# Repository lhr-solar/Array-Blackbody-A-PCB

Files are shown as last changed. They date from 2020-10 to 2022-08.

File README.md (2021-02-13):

# RTD and Irradiance Sensor Board

This repository contains the following files for the RTD/Irradiance Sensor HW:

- Schematic
- Layout
- Datasheets

Also a good resource is the
[Irradiance/RTD Board Parts List](https://docs.google.com/spreadsheets/d/1edYMT-QyYtll1uI2qYTIh2mhwAQPUqRFkjrvS2jViS4/edit?usp=sharing);
this is the source of truth for the schematic and layout and should be consulted
and updated by anyone doing revisions on the board. As good practice, make sure
your updates to the parts list, when finalized, gets a new named version in the
version history.

A couple other important sections for engineers who are improving this board are
below.

- Versioning
- Maintainers
- Errata and Changes
- Suggested Improvements
- Ordering Instructions
- Assembly Instructions

---

## Maintainers

The last maintainer of this project was Matthew Yu (Array Lead 2020) as of
12/13/2020. His email is matthewjkyu@gmail.com.

Also a useful point of contact is Professor Gary Hallock, who advised Matthew
and worked with the several former senior design teams and solar car class
groups who developed this board.

---

## Versioning, Errata, and Changes

This board has separate versions for the schematic, parts list, and layout. We
use [semantic versioning](https://semver.org/) to denote between versions.

We also follow the mutually inclusive versioning procedure agreed upon in this
[issue](https://github.com/lhr-solar/Electronics/issues/40).

### Versioning

The board schematic is currently on **Version 1.0.0**.

The board layout is currently on **Version 1.0.0**.

The parts list is currently on **Version 1.0.0**.

### Schematic

- **Rev 1.0.0**:
  - None as of 12/13/2020, but then the board hasn't been assembled and tested
    yet.

### Layout

- **Rev 1.0.0**:
  - None as of 12/13/2020, but then the board hasn't been assembled and tested
    yet.

### Parts List

- **Rev 1.0.0**:
  - Populated and ready for ordering (sans snubber caps and resistors).

---

## Suggested Improvements

This is a list of changes we can make to the board in future versions to improve
it in various ways. Some of these are functional, others are purely aesthetic.

1. Use a multiplexer to route RTDs to a single RTD-to-digital-converter chip.
   This would reduce our 8 chips into 1 and potentially cut down board size by
   more than 50%. This may also have advantages for digital signal integrity by
   drastically reducing trace length. Oh, and a large cost reduction.
2. Rename the project from RTDTemp to RTD_Irradiance_Board. Make sure you do
   this on a feature branch of the repo so you can revert to a previous version
   if you break things.

---

## Ordering Instructions

Ordering the board will vary from distributor to distributor; some will take the
KiCAD project directly, others require Gerber files. If they require gerber
files, some will require specific naming conventions for each layer.

If they take KiCAD projects directly, that should be what you prefer. Package
`RTDTemp.pro`, `RTDTemp.kicad_pcb`, and `RTDTemp.sch` together into a zip file (i.e.
`RTDTemp.zip`) and upload it. Double check the layers they detect to ensure that
everything looks correct. If they aren't interpreted correctly, use the Gerber
files instead.

The Gerber files are grouped together into the 'Gerber/' folder. The layers you
want are:

- Front/Top Copper,
- Back/Bottom Copper,
- Front/Top Mask,
- Back/Bottom Mask,
- Front/Top Silkscreen,
- Back/Bottom Silkscreen,
- Edge Cuts (i.e. board outline)

You may also want the Front/Top Fabrication layer if you're submitting to a
manufacturer that will place and solder your components for you, but that's not
strictly necessary.

The Gerber files I've generated should be named appropriately for most
manufacturers, however they may prefer slightly different conventions. Double
check their requirements, make any necessary adjustments to file names, then zip
up all of the gerber files and upload that.

Some examples of alternate conventions:

- Some want the board outline to have the extension '.gko'.
- Some want all layers to have the same base name (i.e. 'RTDTemp.gbl',
  'RTDTemp.gbs', etc.).
- Some want the drill files combined (in which case you'll need to regenerate
  the drill file with plated and nonplated holes combined).
- Some want the drill files to have the extension '.txt'.

If you need to regenerate the Gerber files for whatever reason, the defaults
saved to the PCB file should be sufficient. However, in case these are lost,
here are the important parts:

- Set Output Directory to "Gerber/"
- Uncheck "Plot sheet reference on all layers"
- Check "Exclude PCB edge layer from other layers"
- Check "Use Protel filename extensions"

-or the drill files:

- Set Output Directory to "Gerber/"
- Set Drill Units to "Inches"
- Set Zeros Format to "Decimal format"
- Set Drill Map File Format to "PostScript"
- Uncheck "Mirror y axis"

These settings should work, but double check with your manufacturer that these
settings are correct before you order.

---

## Assembly and Testing

The board should be assembled and tested in sections to ensure proper
functioning. Assembly should go through the following sections in order:

1. Power Regulation
2. LEDs
3. Nucleo Connections
4. RTD Sensors
5. Irradiance Sensors
6. CAN

### Step by Step Instructions

It's highly recommended to pull up the schematic and layout side by side while
assembling and testing the board. As a tip, you can click on the schematic
symbol, and if the layout window is open, it'll jump to that part on the layout.
Also hide everything except the Silkscreen or Fabrication layer (of the right
side of the PCB) to remove any clutter from the layout.

Also, if you find any discrepancies between these instructions and the board
layout, please file a PR or issue so it can be fixed!

1. Initial Board Checks

   Before installing anything, check for power shorts where there shouldn't be:
   - Between Car Power +12V and GNDPWR.
   - Between Device Power +9VA and GNDREF.
   - Between Car Power +12V and Device Power +9VA.
   - Between Car Power GNDPWR and Device Power GNDREF.
   - Between CAN Iso Vout and GndOut
   - Between CAN Iso Vin and GndIn
   - Between CAN Iso Vout and Vin
   - Between CAN Iso GndOut and GndIn

   Other important shorts to check for and eliminate:
   - Between CAN H and L
   - On each Nucleo board, between A4 and D4 (shorted by SB18)
   - On each Nucleo board, between A5 and D5 (shorted by SB16)

2. Assembling Power Regulation
   1. Solder the smallest components first: L1, C1, C2, C3, C4. These can be
      done in any order.
   2. Solder test points: TP2, TP3, TP4, TP5. These can be done in any order.
   3. Solder power regulator U2.
   4. Solder the connector J3.
   5. Test for the following shorts:
      - Between Car Power +12V and GNDPWR.
      - Between Device Power +9VA and GNDREF.
      - Between Car Power +12V and Device Power +9VA.
      - Between Car Power GNDPWR and Device Power GNDREF.
      - Between pins on U2.
   6. Connect +12V to the connector and verify that +9VA is at TP4.
   7. As a bonus, somehow make some noise at +12V and see how stable +9VA is.

3. LEDs
   1. Solder the smallest components first: R3 - R8 and LED1 - LED6. You get the
      drill by now.
   2. Check for shorts across each resistor-LED pair. As a tip, the LED
      reference number is always two less than the resistor reference number.
   3. Further testing on these will occur in the next step.

4. Nucleo Connections
   1. Solder the smallest components first: SW, J1, J2, R1, R2. You get the
      drill by now.
   2. Solder the headers for the Nucleo (U1) and make sure they are upright.
   3. Test for the following shorts:
      - Across SW1 (shorts only when pushed)
      - Between pins on U1 (as a bonus)
   4. Plug in the Nucleo and then test for shorts between D4 and A4 and between
      D5 and A5. If there are shorts here, you will need to remove SB18 or SB16,
      respectively, from the Nucleo board.

      **YOU MUST DO THIS FOR EVERY UNIQUE NUCLEO YOU PLUG INTO THE BOARD.**

   5. Load up the Nucleo with a test program to cycle LED pins and outputs a PWM
      signal with a non-trivial duty cycle and see if they light up/are correct
      on an O-scope. Unplug the Nucleo from USB, and connect 12V to the Car
      Power Connector J1 (But not both!). Make sure the Nucleo powers on again
      and the test program works as expected.
   6. Remove the Nucleo and all sources of power before further assembly.

5. RTD Sensors

   It's recommended to do one of these sensors at a time.

   1. Pick a sensor. We'll use the first sensor (sensor 0) as an example.
   2. Solder the smallest components first: RTD0_C1, RTD0_C2, RTD0_C3, RTD0_R1.
   3. Solder the chip RTD0_U1.
   4. Solder the connector RTD0_J1.
   5. Test for shorts across the pins on U1, and that we have a connection
      between pads 2 and 3 and the +3.3V pin of the Nucleo (after
      plugging it in, but not powering it).
   6. You can then load up a test program to communicate with the chip via SPI.
      If you have an Arduino Uno, you can try using this
      [test program](https://github.com/olewolf/arduino-max31865)
      written by `olewolf`. You can use the Nucleo headers to access the
      relevant pins of the chips - the pin mapping is described in the
      `Examples/Read_Temperature/Read_Temperature.ino`.
   7. If test software for the Nucleo has been written, you can potentially skip
      step 6 and use the Nucleo with the software flashed directly. Although
      going back to step 6 could be useful for debugging if you have issues
      here.

6. CAN Circuit

   1. Solder chip U3 **first** and test for shorts across adjacent pins.
   2. Solder the smallest components: C5 - C12, L2, L3, R10, R11.
   3. Solder bridge R9.
   4. Solder test points TP5 - TP12.
   5. Solder the chip U4.
   6. Solder the termination header JP1.
   7. Solder the CAN Connectors J4, J5.
   8. Test for the following shorts:
      - Between CAN_H and CAN_L.
      - Between CAN_Tx, CAN_Rx.
      - +5V and GNDREF (Power side).
      - 5V and GND (CAN side).
      - Across adjacent pins in U3, U4.
   9. Plug in the Nucleo, connect J4/J5 to a CAN bus, and run a CAN
      communication test to ensure that the installed CAN circuitry is
      functional.
   10. Remove any power, the Nucleo, and then CAN connections before further
       assembly.

7. Post checks

   Now that you've made it to the end (we hope) of assembly and preliminary
   testing, you should do a couple things before running full RTDTemp tests and
   running RTDTemp algorithms on it.

   1. First, check the board for obvious soldering defections like burnt traces
      or exposed component legs. Make sure those still work. For any solder
      bridges that shouldn't fix, you should fix them. Or get somebody who's
      better than you to fix them.
   2. Check to see if you have any remaining parts hiding in the pile of
      plastic packages you probably received. Any remaining parts should
      probably be a cause for concern (unless you knew you were going to blow
      something and had the foresight to get extra) and you should definitely
      see where they might have come from.

      The RTDTemp Parts list is **THE** definite source of truth, and tells you
      where each part is tied to which reference and thus their position on the
      layout. Check there first before running to the electrical lead to help
      you.
   3. It might be a good idea if you're bored to run any electrical/short tests
      that were described earlier in these instructions. There's always a small
      chance that some assembly you did later on broke/removed/damaged previous
      parts.

You now have a completed RTDTemp (I hope) and I wish you luck in your future
solar car endeavors!

This assembly guide was last modified *12/13/2020* by **Matthew Yu**.

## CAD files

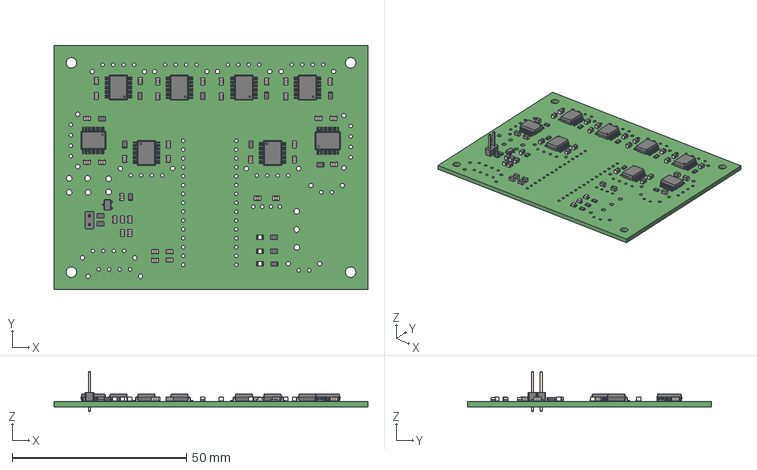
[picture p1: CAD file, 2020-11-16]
RTDTemp.step
90.0 x 70.0 x 11.5 mm

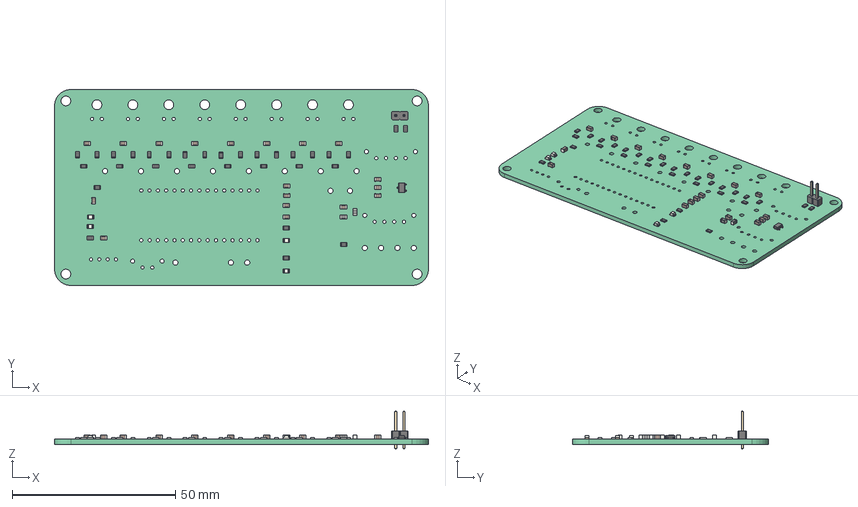
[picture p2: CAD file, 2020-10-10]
RTD.step
114.5 x 60.0 x 11.5 mm
Local_CS_a89f
Pcb_a89f
PCB_Sketch_a89f
U7_SOT_23W_5E47511B
JP1_PinHeader_1x02_P254mm_Vertical_5E474AD0
C16_C_0805_2012Metric_5E475BC1
C15_C_0805_2012Metric_5E4747D3
C14_C_0805_2012Metric_5E4747C2
C13_C_0805_2012Metric_5E4747B1
C7_C_0805_2012Metric_5E4003D7
C6_C_0805_2012Metric_5E4003C6
R32_R_0805_2012Metric_5E370AB1
R31_R_0805_2012Metric_5E370AA0
R30_R_0805_2012Metric_5E370A8F
R29_R_0805_2012Metric_5E370A7E
R28_R_0805_2012Metric_5E370A6D
R27_R_0805_2012Metric_5E370A5C
R26_R_0805_2012Metric_5E370A4B
R24_R_0805_2012Metric_5E370A3A
R23_R_0805_2012Metric_5E370A29
R19_R_0805_2012Metric_5E370A18
R18_R_0805_2012Metric_5E370A07
R17_R_0805_2012Metric_5E3709F6
R16_R_0805_2012Metric_5E3F5E9A
R15_R_0805_2012Metric_5E3709D4
R13_R_0805_2012Metric_5E3709C3
R12_R_0805_2012Metric_5E3709B2
R11_R_0805_2012Metric_5E3709A1
R8_R_0805_2012Metric_5E370990
R6_R_0805_2012Metric_5E37097F
R5_R_0805_2012Metric_5E37096E
R4_R_0805_2012Metric_5E3EF439
R3_R_0805_2012Metric_5E37094C
R2_R_0805_2012Metric_5E3F3787
R1_R_0805_2012Metric_5E37092A
C19_C_0805_2012Metric_5E3F6AFD
C18_C_0805_2012Metric_5E3707F4
C17_C_0805_2012Metric_5E3707E3
C5_C_0805_2012Metric_5E3707D2
C4_C_0805_2012Metric_5E3EF89F
C3_C_0805_2012Metric_5E3707B0
C2_C_0805_2012Metric_5E37079F
C1_C_0805_2012Metric_5E37078E
C9_C_0805_2012Metric_5E49071F
C10_C_0805_2012Metric_5E49072F
C11_C_0805_2012Metric_5E49073F
C12_C_0805_2012Metric_5E49074F
L2_L_0805_2012Metric_5E490782
L3_L_0805_2012Metric_5E490792
LED3_LED_0805_2012Metric_5E4907A2
LED7_LED_0805_2012Metric_5E4907B4
LED8_LED_0805_2012Metric_5E4907C6
LED9_LED_0805_2012Metric_5E4907D8
R9_R_0805_2012Metric_5E4907EA
R10_R_0805_2012Metric_5E4907FA
R14_R_0805_2012Metric_5E49080A
R20_R_0805_2012Metric_5E49081A
R21_R_0805_2012Metric_5E49082A
R22_R_0805_2012Metric_5E49083A
R25_R_0805_2012Metric_5E49084A

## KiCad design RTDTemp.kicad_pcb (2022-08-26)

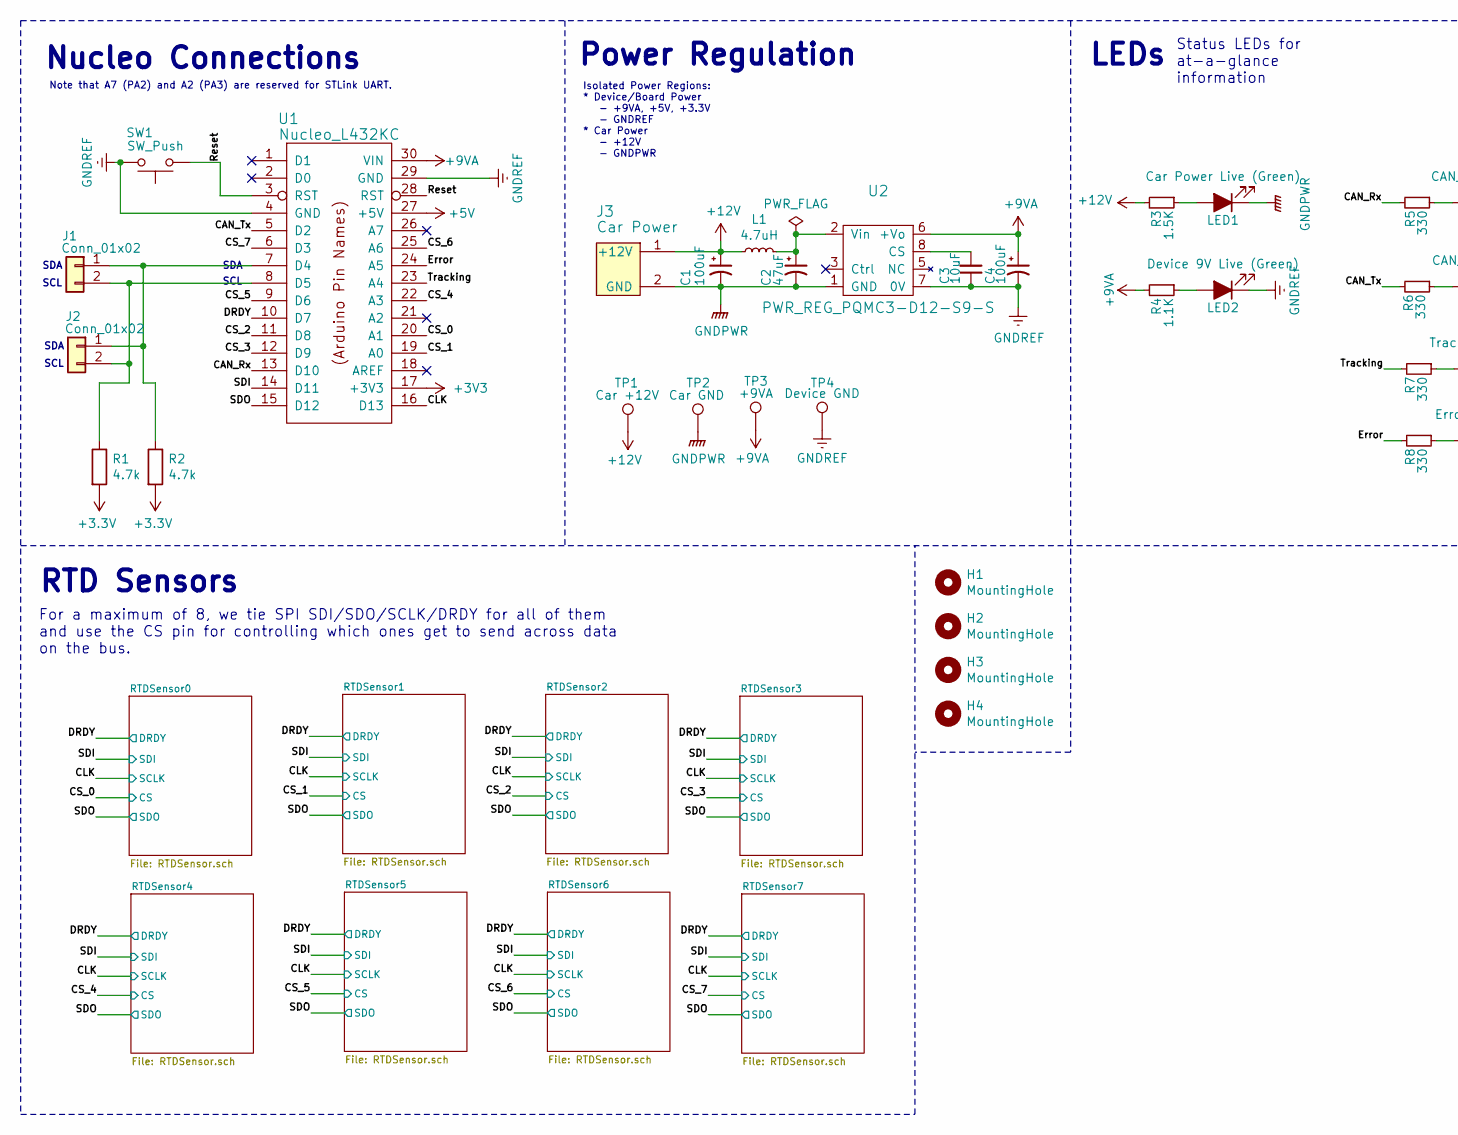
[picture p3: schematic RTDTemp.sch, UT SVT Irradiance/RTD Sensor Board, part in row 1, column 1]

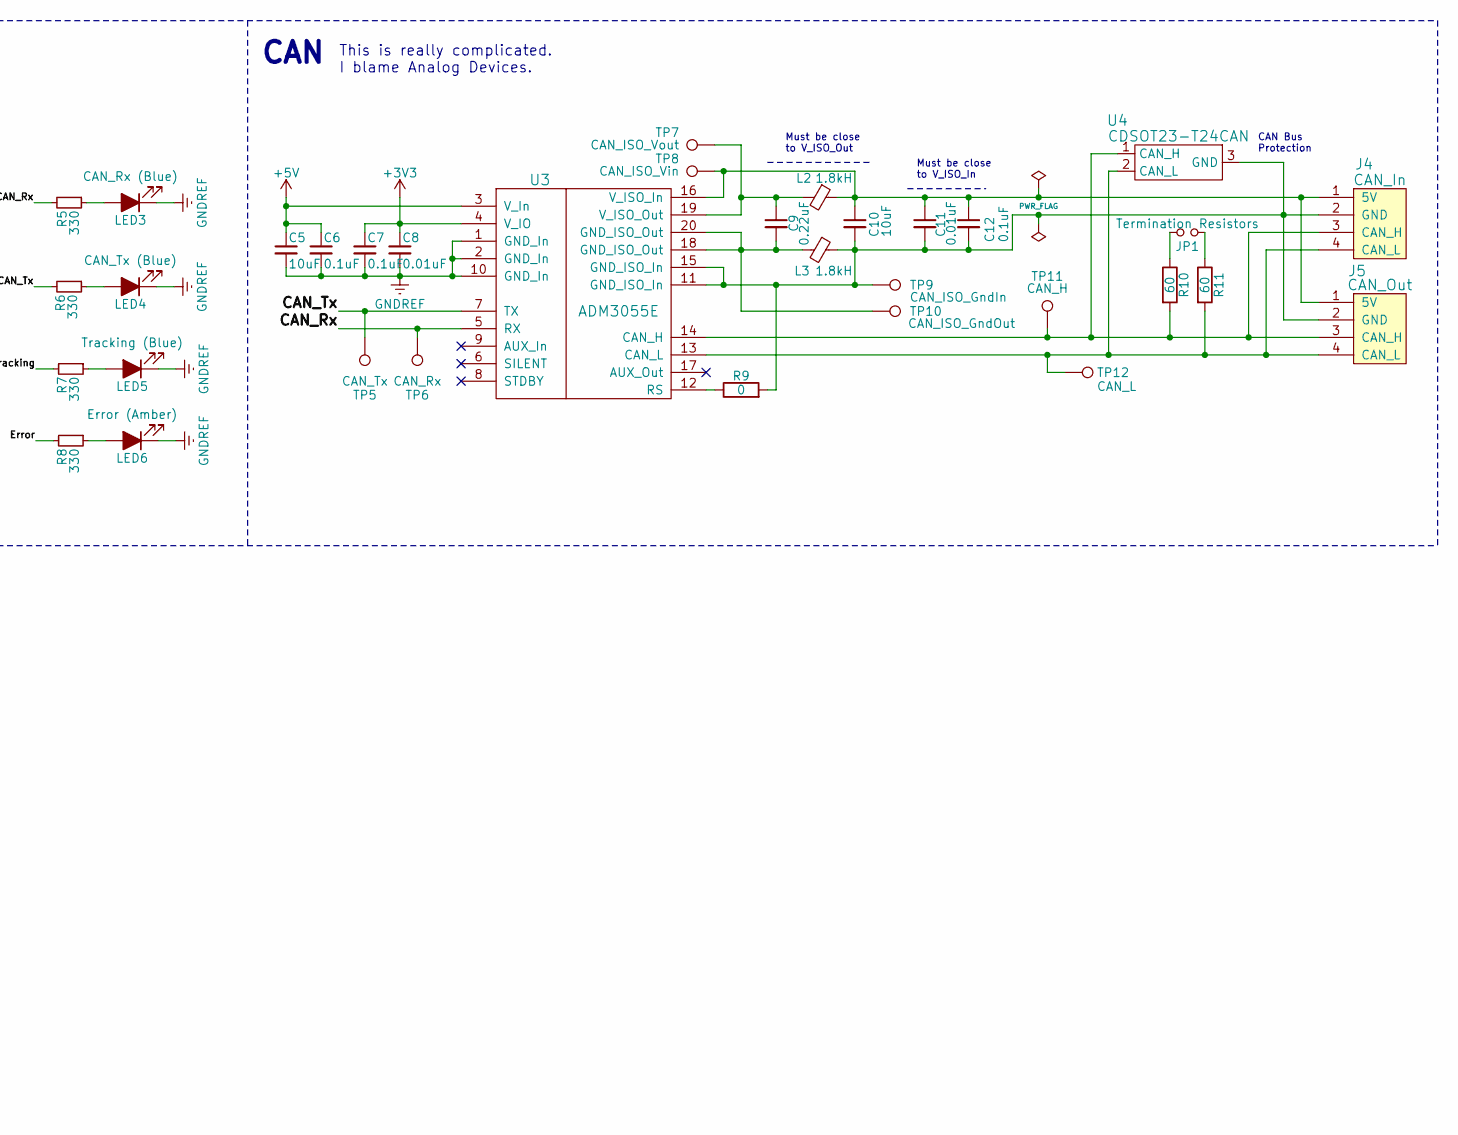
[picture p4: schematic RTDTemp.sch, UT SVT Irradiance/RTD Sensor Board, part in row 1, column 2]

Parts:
C1, C4: 100uF; C_1210_3225Metric
C2: 47uF; C_1210_3225Metric
C3, C5, C10: 10uF; C_0805_2012Metric
C6, C7, C12: 0.1uF; C_0805_2012Metric
C8, C11: 0.01uF; C_0805_2012Metric
C9: 0.22uF; C_0805_2012Metric
H1, H2, H3, H4: MountingHole; MountingHole_3mm
J1, J2: Conn_01x02; Molex_Micro-Fit_3.0_43650-0215_1x02_P3.00mm_Vertical
J3: Car Power; Molex_Micro-Fit_3.0_43650-0215_1x02_P3.00mm_Vertical
J4: CAN_In; Molex_Micro-Fit_3.0_43650-0415_1x04_P3.00mm_Vertical
J5: CAN_Out; Molex_Micro-Fit_3.0_43650-0415_1x04_P3.00mm_Vertical
JP1: Termination Resistors; PinHeader_1x02_P2.54mm_Vertical
L1: 4.7uH; L_0805_2012Metric
L2, L3: 1.8kH; L_0805_2012Metric
LED1: Car Power Live (Green); LED_0805_2012Metric
LED2: Device 9V Live (Green); LED_0805_2012Metric
LED3: CAN_Rx (Blue); LED_0805_2012Metric
LED4: CAN_Tx (Blue); LED_0805_2012Metric
LED5: Tracking (Blue); LED_0805_2012Metric
LED6: Error (Amber); LED_0805_2012Metric
R1, R2: 4.7k; R_0805_2012Metric
R3: 1.5K; R_0805_2012Metric
R4: 1.1K; R_0805_2012Metric
R5, R6, R7, R8: 330; R_0805_2012Metric
R9: 0; R_0805_2012Metric
R10, R11: 60; R_0805_2012Metric
SW1: SW_Push; SW_PUSH_6mm
TP1: Car +12V; TestPoint_Keystone_5005-5009_Compact
TP2: Car GND; TestPoint_Keystone_5005-5009_Compact
TP3: +9VA; TestPoint_Keystone_5005-5009_Compact
TP4: Device GND; TestPoint_Keystone_5005-5009_Compact
TP5: CAN_Tx; TestPoint_Keystone_5005-5009_Compact
TP6: CAN_Rx; TestPoint_Keystone_5005-5009_Compact
TP7: CAN_ISO_Vout; TestPoint_Keystone_5005-5009_Compact
TP8: CAN_ISO_Vin; TestPoint_Keystone_5005-5009_Compact
TP9: CAN_ISO_GndIn; TestPoint_Keystone_5005-5009_Compact
TP10: CAN_ISO_GndOut; TestPoint_Keystone_5005-5009_Compact
TP11: CAN_H; TestPoint_Keystone_5005-5009_Compact
TP12: CAN_L; TestPoint_Keystone_5005-5009_Compact
U1: Nucleo_L432KC; MODULE_NUCLEO-L432KC
U2: PWR_REG_PQMC3-D12-S9-S; 490_PQMC3_D12_S12_S
U3: ADM3055E; ADM3055EBRIZ
U4: CDSOT23-T24CAN; SOT-23

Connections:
+5V: C5.1, C6.1, U1.27 (+5V), U3.3 (V_In)
+9VA: C4.1, R4.2, TP3.1, U1.30 (VIN), U2.6 (+Vo)
+12V: C1.1, J3.1 (+12V), L1.1, R3.2, TP1.1
/CAN_Rx: R5.2, TP6.1, U1.13 (D10), U3.5 (RX)
/CAN_Tx: R6.2, TP5.1, U1.5 (D2), U3.7 (TX)
/CLK: U1.16 (D13); also elsewhere on the board
/CS_0: U1.20 (A1); also elsewhere on the board
/CS_1: U1.19 (A0); also elsewhere on the board
/CS_2: U1.11 (D8); also elsewhere on the board
/CS_3: U1.12 (D9); also elsewhere on the board
/CS_4: U1.22 (A3); also elsewhere on the board
/CS_5: U1.9 (D6); also elsewhere on the board
/CS_6: U1.25 (A6); also elsewhere on the board
/CS_7: U1.6 (D3); also elsewhere on the board
/DRDY: U1.10 (D7); also elsewhere on the board
/Error: R8.2, U1.24 (A5)
/Reset: SW1.1, U1.3 (RST), U1.28 (RST)
/SDI: U1.14 (D11); also elsewhere on the board
/SDO: U1.15 (D12); also elsewhere on the board
/Tracking: R7.2, U1.23 (A4)
GNDPWR: C1.2, C2.2, J3.2 (GND), LED1.1 (K), TP2.1, U2.1 (GND)
GNDREF: C3.1, C4.2, C5.2, C6.2, C7.2, C8.2, LED2.1 (K), LED3.1 (K), LED4.1 (K), LED5.1 (K), LED6.1 (K), SW1.2, TP4.1, U1.4 (GND), U1.29 (GND), U2.7 (0V), U3.1 (GND_In), U3.2 (GND_In), U3.10 (GND_In); also elsewhere on the board
unnamed: C2.1, L1.2, U2.2 (Vin)
unnamed: C3.2, U2.8 (CS)
unnamed: C9.1, L2.2, TP7.1, U3.19 (V_ISO_Out)
unnamed: C9.2, L3.2, TP10.1, U3.18 (GND_ISO_Out), U3.20 (GND_ISO_Out)
unnamed: C10.1, C11.1, C12.1, J4.1 (5V), J5.1 (5V), L2.1, TP8.1, U3.16 (V_ISO_In)
unnamed: C10.2, C11.2, C12.2, J4.2 (GND), J5.2 (GND), L3.1, R9.2, TP9.1, U3.11 (GND_ISO_In), U3.15 (GND_ISO_In), U4.3 (GND)
unnamed: J1.1, J2.1, R2.1, U1.7 (D4)
unnamed: J1.2, J2.2, R1.1, U1.8 (D5)
unnamed: J4.3 (CAN_H), J5.3 (CAN_H), R10.2, TP11.1, U3.14 (CAN_H), U4.1 (CAN_H)
unnamed: J4.4 (CAN_L), J5.4 (CAN_L), R11.2, TP12.1, U3.13 (CAN_L), U4.2 (CAN_L)
unnamed: JP1.1, R11.1
unnamed: JP1.2, R10.1
unnamed: LED1.2 (A), R3.1
unnamed: LED2.2 (A), R4.1
unnamed: LED3.2 (A), R5.1
unnamed: LED4.2 (A), R6.1
unnamed: LED5.2 (A), R7.1
unnamed: LED6.2 (A), R8.1
unnamed: R9.1, U3.12 (RS)

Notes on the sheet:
RTD Sensors
For a maximum of 8, we tie SPI SDI/SDO/SCLK/DRDY for all of them and use the CS pin for controlling which ones get to send across data on the bus.
CAN Bus Protection
Must be close to V_ISO_In
Must be close to V_ISO_Out
This is really complicated. I blame Analog Devices.
CAN
Nucleo Connections
SDA
SCL
Note that A7 (PA2) and A2 (PA3) are reserved for STLink UART.
Power Regulation
Isolated Power Regions: * Device/Board Power - +9VA, +5V, +3.3V - GNDREF * Car Power - +12V - GNDPWR
LEDs
Status LEDs for at-a-glance information

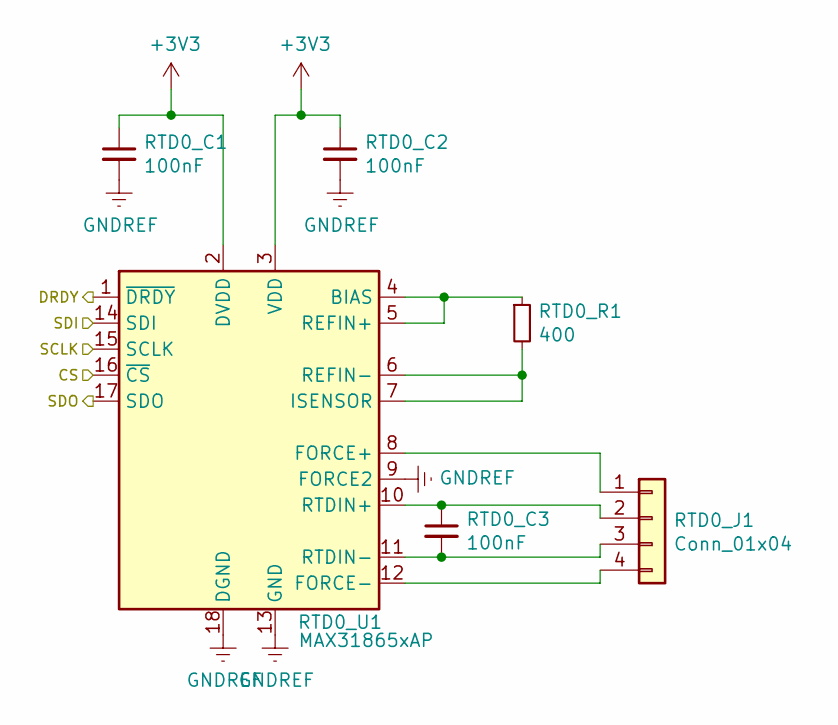
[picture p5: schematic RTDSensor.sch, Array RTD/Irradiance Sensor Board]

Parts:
RTD1_C1, RTD1_C2, RTD1_C3: 100nF; C_0805_2012Metric
RTD1_J1: Conn_01x04; Molex_Micro-Fit_3.0_43650-0415_1x04_P3.00mm_Vertical
RTD1_R1: 400; R_0805_2012Metric
RTD1_U1: MAX31865xAP; SSOP-20_5.3x7.2mm_P0.65mm

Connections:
/CLK: RTD1_U1.15 (SCLK); also elsewhere on the board
/CS_1: RTD1_U1.16 (~CS); also elsewhere on the board
/DRDY: RTD1_U1.1 (~DRDY); also elsewhere on the board
/SDI: RTD1_U1.14 (SDI); also elsewhere on the board
/SDO: RTD1_U1.17 (SDO); also elsewhere on the board
GNDREF: RTD1_C1.2, RTD1_C2.2, RTD1_U1.9 (FORCE2), RTD1_U1.13 (GND), RTD1_U1.18 (DGND), RTD1_U1.19 (GND); also elsewhere on the board
unnamed: RTD1_C3.1, RTD1_J1.2, RTD1_U1.10 (RTDIN+)
unnamed: RTD1_C3.2, RTD1_J1.3, RTD1_U1.11 (RTDIN-)
unnamed: RTD1_J1.1, RTD1_U1.8 (FORCE+)
unnamed: RTD1_J1.4, RTD1_U1.12 (FORCE-)
unnamed: RTD1_R1.1, RTD1_U1.4 (BIAS), RTD1_U1.5 (REFIN+)
unnamed: RTD1_R1.2, RTD1_U1.6 (REFIN-), RTD1_U1.7 (ISENSOR)

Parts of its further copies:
RTD0_C1, RTD0_C2, RTD0_C3, RTD2_C1, RTD2_C2, RTD2_C3, RTD3_C1, RTD3_C2, RTD3_C3, RTD4_C1, RTD4_C2, RTD4_C3, RTD5_C1, RTD5_C2, RTD5_C3, RTD6_C1, RTD6_C2, RTD6_C3, RTD7_C1, RTD7_C2, RTD7_C3: 100nF; C_0805_2012Metric
RTD0_J1, RTD2_J1, RTD3_J1, RTD4_J1, RTD5_J1, RTD6_J1, RTD7_J1: Conn_01x04; Molex_Micro-Fit_3.0_43650-0415_1x04_P3.00mm_Vertical
RTD0_R1, RTD2_R1, RTD3_R1, RTD4_R1, RTD5_R1, RTD6_R1, RTD7_R1: 400; R_0805_2012Metric
RTD0_U1, RTD2_U1, RTD3_U1, RTD4_U1, RTD5_U1, RTD6_U1, RTD7_U1: MAX31865xAP; SSOP-20_5.3x7.2mm_P0.65mm

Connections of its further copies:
/CLK: RTD0_U1.15 (SCLK), RTD2_U1.15 (SCLK), RTD3_U1.15 (SCLK), RTD4_U1.15 (SCLK), RTD5_U1.15 (SCLK), RTD6_U1.15 (SCLK), RTD7_U1.15 (SCLK); also elsewhere on the board
/CS_0: RTD0_U1.16 (~CS); also elsewhere on the board
/CS_2: RTD2_U1.16 (~CS); also elsewhere on the board
/CS_3: RTD3_U1.16 (~CS); also elsewhere on the board
/CS_4: RTD4_U1.16 (~CS); also elsewhere on the board
/CS_5: RTD5_U1.16 (~CS); also elsewhere on the board
/CS_6: RTD6_U1.16 (~CS); also elsewhere on the board
/CS_7: RTD7_U1.16 (~CS); also elsewhere on the board
/DRDY: RTD0_U1.1 (~DRDY), RTD2_U1.1 (~DRDY), RTD3_U1.1 (~DRDY), RTD4_U1.1 (~DRDY), RTD5_U1.1 (~DRDY), RTD6_U1.1 (~DRDY), RTD7_U1.1 (~DRDY); also elsewhere on the board
/SDI: RTD0_U1.14 (SDI), RTD2_U1.14 (SDI), RTD3_U1.14 (SDI), RTD4_U1.14 (SDI), RTD5_U1.14 (SDI), RTD6_U1.14 (SDI), RTD7_U1.14 (SDI); also elsewhere on the board
/SDO: RTD0_U1.17 (SDO), RTD2_U1.17 (SDO), RTD3_U1.17 (SDO), RTD4_U1.17 (SDO), RTD5_U1.17 (SDO), RTD6_U1.17 (SDO), RTD7_U1.17 (SDO); also elsewhere on the board
GNDREF: RTD0_C1.2, RTD0_C2.2, RTD0_U1.9 (FORCE2), RTD0_U1.13 (GND), RTD0_U1.18 (DGND), RTD0_U1.19 (GND), RTD2_C1.2, RTD2_C2.2, RTD2_U1.9 (FORCE2), RTD2_U1.13 (GND), RTD2_U1.18 (DGND), RTD2_U1.19 (GND), RTD3_C1.2, RTD3_C2.2, RTD3_U1.9 (FORCE2), RTD3_U1.13 (GND), RTD3_U1.18 (DGND), RTD3_U1.19 (GND), RTD4_C1.2, RTD4_C2.2, RTD4_U1.9 (FORCE2), RTD4_U1.13 (GND), RTD4_U1.18 (DGND), RTD4_U1.19 (GND), RTD5_C1.2, RTD5_C2.2, RTD5_U1.9 (FORCE2), RTD5_U1.13 (GND), RTD5_U1.18 (DGND), RTD5_U1.19 (GND), RTD6_C1.2, RTD6_C2.2, RTD6_U1.9 (FORCE2), RTD6_U1.13 (GND), RTD6_U1.18 (DGND), RTD6_U1.19 (GND), RTD7_C1.2, RTD7_C2.2, RTD7_U1.9 (FORCE2), RTD7_U1.13 (GND), RTD7_U1.18 (DGND), RTD7_U1.19 (GND); also elsewhere on the board
unnamed: RTD0_C3.1, RTD0_J1.2, RTD0_U1.10 (RTDIN+)
unnamed: RTD0_C3.2, RTD0_J1.3, RTD0_U1.11 (RTDIN-)
unnamed: RTD0_J1.1, RTD0_U1.8 (FORCE+)
unnamed: RTD0_J1.4, RTD0_U1.12 (FORCE-)
unnamed: RTD0_R1.1, RTD0_U1.4 (BIAS), RTD0_U1.5 (REFIN+)
unnamed: RTD0_R1.2, RTD0_U1.6 (REFIN-), RTD0_U1.7 (ISENSOR)
unnamed: RTD2_C3.1, RTD2_J1.2, RTD2_U1.10 (RTDIN+)
unnamed: RTD2_C3.2, RTD2_J1.3, RTD2_U1.11 (RTDIN-)
unnamed: RTD2_J1.1, RTD2_U1.8 (FORCE+)
unnamed: RTD2_J1.4, RTD2_U1.12 (FORCE-)
unnamed: RTD2_R1.1, RTD2_U1.4 (BIAS), RTD2_U1.5 (REFIN+)
unnamed: RTD2_R1.2, RTD2_U1.6 (REFIN-), RTD2_U1.7 (ISENSOR)
unnamed: RTD3_C3.1, RTD3_J1.2, RTD3_U1.10 (RTDIN+)
unnamed: RTD3_C3.2, RTD3_J1.3, RTD3_U1.11 (RTDIN-)
unnamed: RTD3_J1.1, RTD3_U1.8 (FORCE+)
unnamed: RTD3_J1.4, RTD3_U1.12 (FORCE-)
unnamed: RTD3_R1.1, RTD3_U1.4 (BIAS), RTD3_U1.5 (REFIN+)
unnamed: RTD3_R1.2, RTD3_U1.6 (REFIN-), RTD3_U1.7 (ISENSOR)
unnamed: RTD4_C3.1, RTD4_J1.2, RTD4_U1.10 (RTDIN+)
unnamed: RTD4_C3.2, RTD4_J1.3, RTD4_U1.11 (RTDIN-)
unnamed: RTD4_J1.1, RTD4_U1.8 (FORCE+)
unnamed: RTD4_J1.4, RTD4_U1.12 (FORCE-)
unnamed: RTD4_R1.1, RTD4_U1.4 (BIAS), RTD4_U1.5 (REFIN+)
unnamed: RTD4_R1.2, RTD4_U1.6 (REFIN-), RTD4_U1.7 (ISENSOR)
unnamed: RTD5_C3.1, RTD5_J1.2, RTD5_U1.10 (RTDIN+)
unnamed: RTD5_C3.2, RTD5_J1.3, RTD5_U1.11 (RTDIN-)
unnamed: RTD5_J1.1, RTD5_U1.8 (FORCE+)
unnamed: RTD5_J1.4, RTD5_U1.12 (FORCE-)
unnamed: RTD5_R1.1, RTD5_U1.4 (BIAS), RTD5_U1.5 (REFIN+)
unnamed: RTD5_R1.2, RTD5_U1.6 (REFIN-), RTD5_U1.7 (ISENSOR)
unnamed: RTD6_C3.1, RTD6_J1.2, RTD6_U1.10 (RTDIN+)
unnamed: RTD6_C3.2, RTD6_J1.3, RTD6_U1.11 (RTDIN-)
unnamed: RTD6_J1.1, RTD6_U1.8 (FORCE+)
unnamed: RTD6_J1.4, RTD6_U1.12 (FORCE-)
unnamed: RTD6_R1.1, RTD6_U1.4 (BIAS), RTD6_U1.5 (REFIN+)
unnamed: RTD6_R1.2, RTD6_U1.6 (REFIN-), RTD6_U1.7 (ISENSOR)
unnamed: RTD7_C3.1, RTD7_J1.2, RTD7_U1.10 (RTDIN+)
unnamed: RTD7_C3.2, RTD7_J1.3, RTD7_U1.11 (RTDIN-)
unnamed: RTD7_J1.1, RTD7_U1.8 (FORCE+)
unnamed: RTD7_J1.4, RTD7_U1.12 (FORCE-)
unnamed: RTD7_R1.1, RTD7_U1.4 (BIAS), RTD7_U1.5 (REFIN+)
unnamed: RTD7_R1.2, RTD7_U1.6 (REFIN-), RTD7_U1.7 (ISENSOR)

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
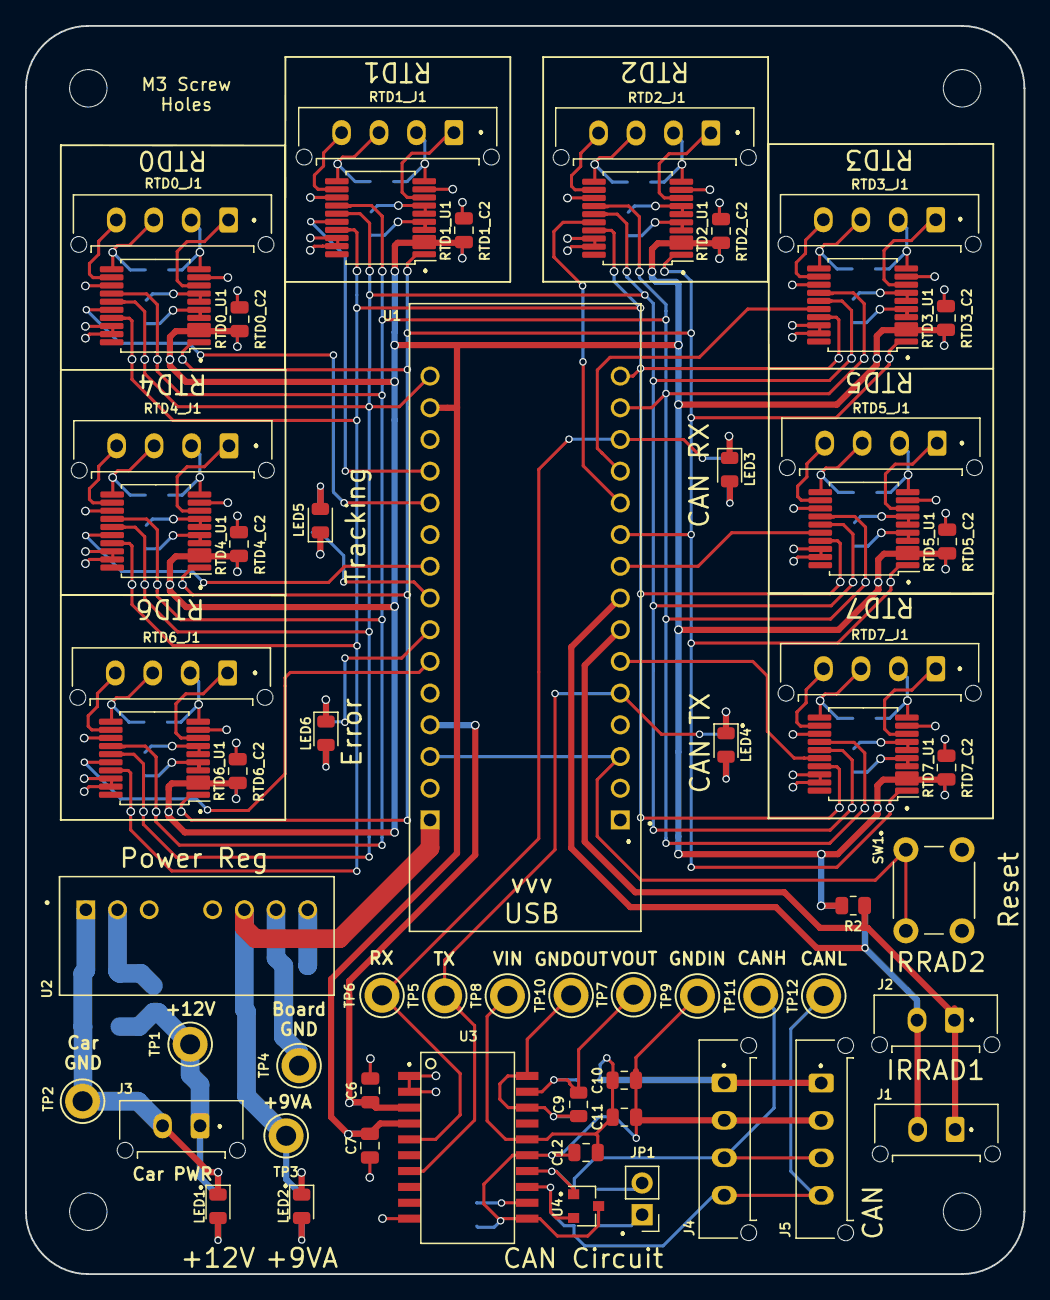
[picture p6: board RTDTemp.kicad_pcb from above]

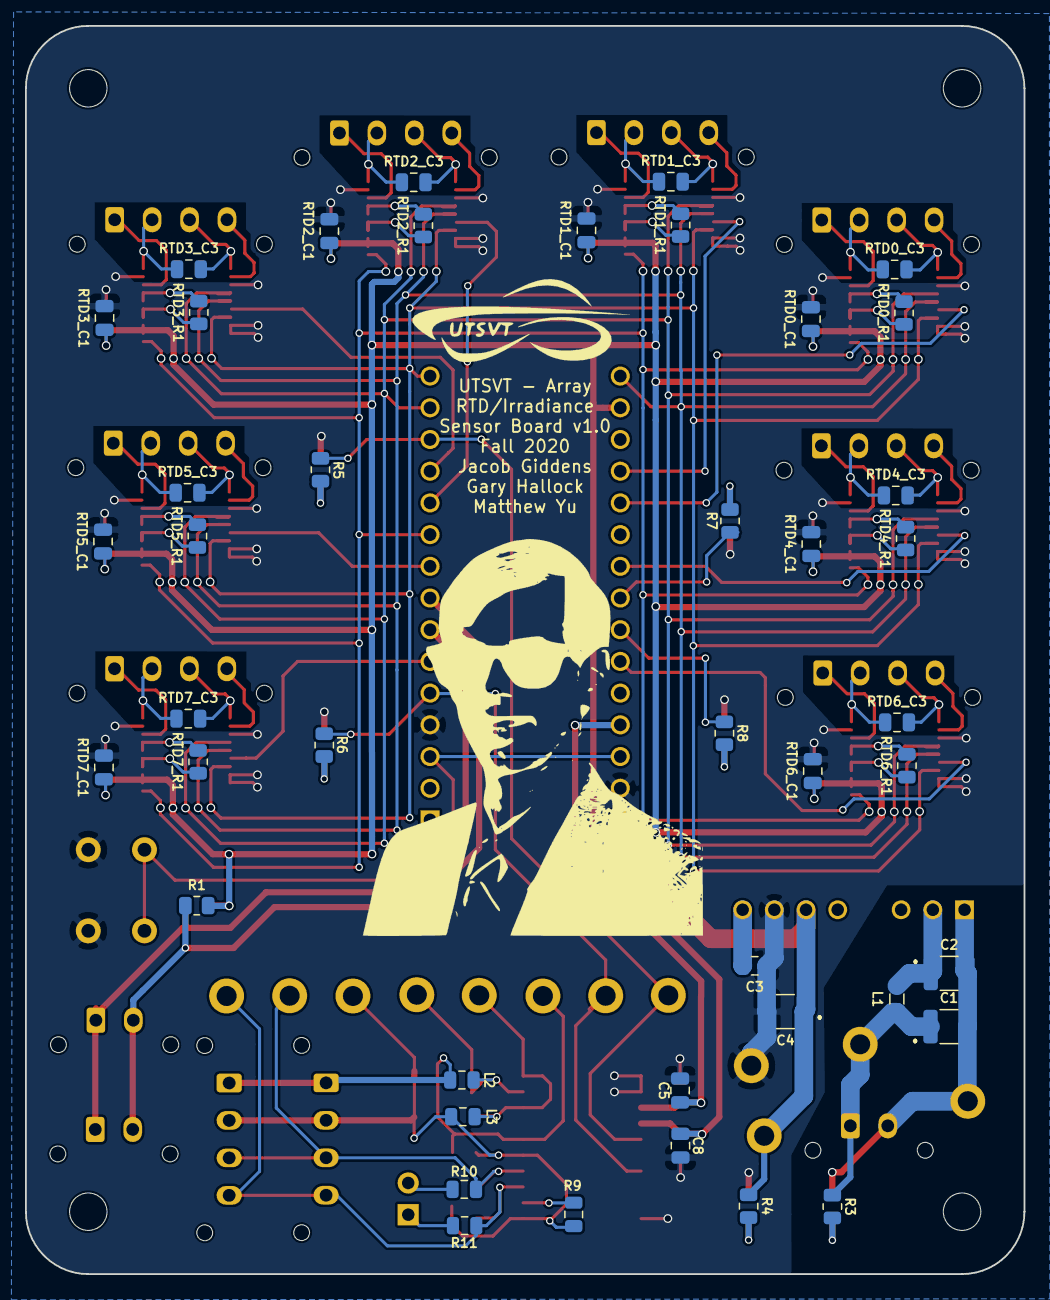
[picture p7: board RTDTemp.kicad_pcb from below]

Board: 2 copper layers, 80.0 x 100.0 mm, 107 parts (43 on the bottom side), 90 nets.

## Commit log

2020-08-02 Adapt RTD to the new repository.
    [BOM.csv, BPS-Nucleo.kicad_pcb, BPS-Nucleo.sch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]
2020-10-10 Add the STEP model
    [RTD.step]
2020-10-28 Started RTD board layout update
    [RTDTemp.kicad_pcb, RTDTemp.sch]
2020-11-01 reset references for rtd specific components, preliminary layout of half of the RTD subcircuits
    [RTDTemp.kicad_pcb, RTDTemp.sch]
2020-11-07 Updated footprints and layout
    [RTDTemp.kicad_pcb]
2020-11-07 Arragned Board
    Arragned Board, room for optimization
    [RTDTemp.kicad_pcb, RTDTemp.sch]
2020-11-14 Finished Optimization, Edge cuts, and Placed Drill Holes
    Optimized the space as best as I could. Some more space could possibly be saved, or maybe some connections could be made better.
    Made the Edge Cuts for the boards. Dimensions right now are 70mm*90mm
    Placed Mounting Holes 5mm*5mm away from the corners of the board.
    [RTDTemp.kicad_pcb]
2020-11-16 cleanup of edge silkscreen and slight component reposition
    [RTDTemp.kicad_pcb, RTDTemp.step]
2020-12-12 PR ready RTD/Irradiance Sensor Board. Added extra mounts for irradiance I2C and updated power reg to match MPPT. Also cleaner layout.
    [MPPT-2019-09-15-22-10-50.sch, MPPT-2020-02-01-15-30-23.sch, MPPT-2020-02-01-15-58-51.sch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]
2020-12-12 Addressed review.
    [RTDSensor.sch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]
2020-12-14 Updated README with assembly and testing instructions.
    [RTDSensor.sch, RTDTemp.kicad_pcb, RTDTemp.sch]
2021-01-14 Added zip and step files
    [RTDTemp.kicad_pcb, RTDTemp.sch]
2021-03-07 Refill layers and rebuild gerbers.
    [RTDTemp-B_Cu.gbl, RTDTemp-B_Mask.gbs, RTDTemp-B_SilkS.gbo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]
